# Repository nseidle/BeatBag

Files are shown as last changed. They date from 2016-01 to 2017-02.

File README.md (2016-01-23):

BeatBag - A Speed Bag Counter
=======

BeatBag is a speed bag counter that uses an accelerometer to counts the number hits. It's easily installed ontop of speed bag platform only needing an accelerometer attached to the top of platform. You don't have to alter the hitting surface or change out the swivel.

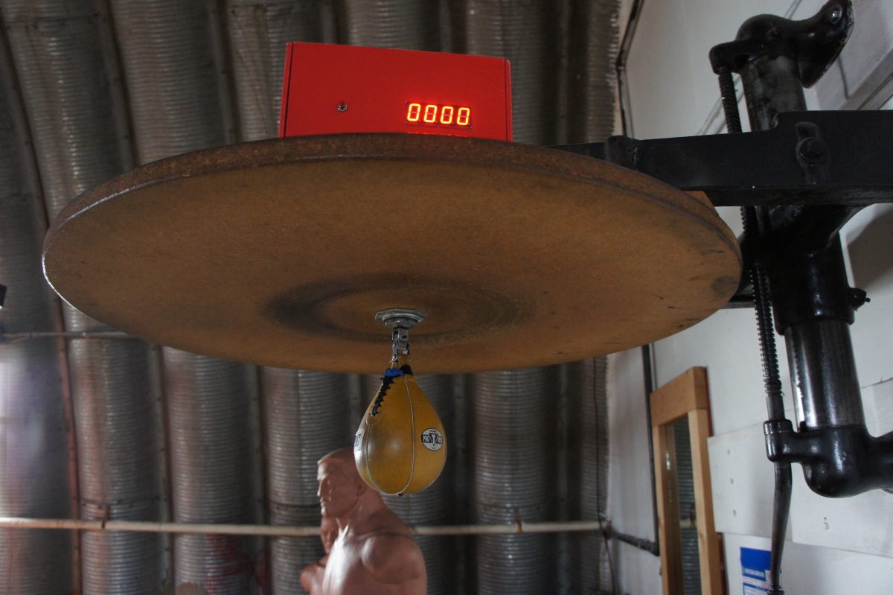
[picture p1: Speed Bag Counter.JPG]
BeatBag on top of a speed bag platform
  

License Information
-------------------

The hardware design and firmware are released under [Creative Commons Share-alike 3.0](http://creativecommons.org/licenses/by-sa/3.0/).  

Feel free to use, distribute, and sell varients of BeatBag. All I ask is that you include attribution of 'Based on BeatBag'.

The BeatBag firmware was created by Nathan Seidle, and is open source so please feel free to do anything you want with it; 
you buy me a beer if you use this and we meet someday ([Beerware license](http://en.wikipedia.org/wiki/Beerware)).

Repository Contents
-------------------
* **/Firmware** 
	* SpeedBagCounter - Firmware that runs on an Arduino or RedBoard
	* MMA8452 - The library to interface to the MMA8452 accelerometer
* **/Hardware** - Hardware design files for the PCB. These are unproven (never been built) but should work. If you're building your own use a RedBoard with OpenSegment and an MMA8452 breakout board.

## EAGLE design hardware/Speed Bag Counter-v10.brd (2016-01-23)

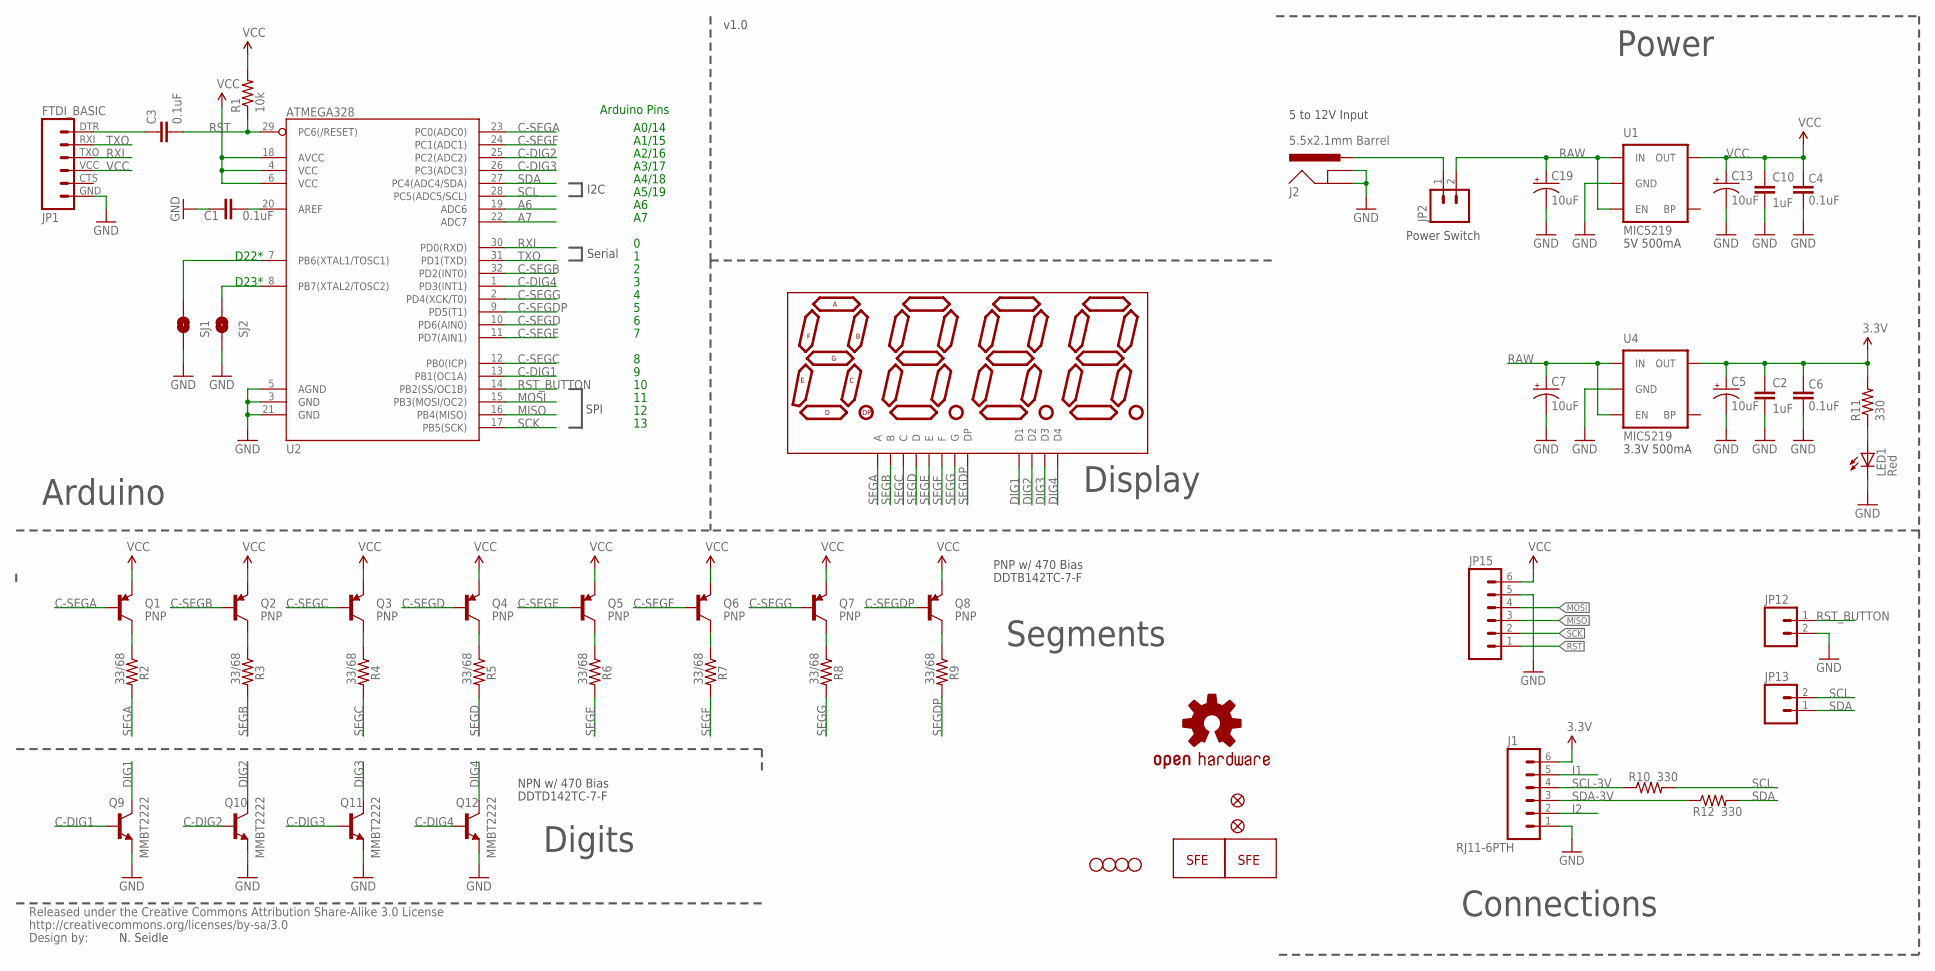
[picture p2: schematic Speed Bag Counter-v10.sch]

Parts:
C1, C3, C4, C6: 0.1uF; 0402-CAP
C2, C10: 1uF; 0402-CAP
C5, C7, C13, C19: 10uF; EIA3216
J1: RJ11-6PTH; RJ11-6
J2: 5.5x2.1mm Barrel; POWER_JACK_SMD
JP1: FTDI_BASIC
JP2, JP12: M02-JST-2MM-SMT; JST-2-SMD
JP3, JP4, JP5, JP6: STAND-OFF
JP7, JP14: FIDUCIALUFIDUCIAL; MICRO-FIDUCIAL
JP13: M02PTH; 1X02
JP15: M06SIP; 1X06
LED1: Red; LED-0603
Q1, Q2, Q3, Q4, Q5, Q6, Q7, Q8: PNP; SOT23-3
Q9, Q10, Q11, Q12: MMBT2222; SOT23-3
R1: 10k; 0402-RES
R2, R3, R4, R5, R6, R7, R8, R9: 33/68; 0402-RES
R10, R11, R12: 330; 0402-RES
SJ1, SJ2: Counter Ctl; SJ_2S-NO
U1, U4: MIC5219; SOT23-5
U2: ATMEGA328; TQFP32-08
U3: 7-SEGMENT-4DIGIT-COUNTERPTH; 7-SEGMENT-4DIGIT-COUNTER
U$2: LOGO-SFESK; SFE-LOGO-FLAME
U$3: CREATIVE_COMMONS
U$4: OSHW-LOGOS; OSHW-LOGO-S
U$7: LOGO-SFENW2; SFE-NEW-WEB

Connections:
3.3V: C2.1, C5.A (+), C6.2, J1.6, R11.2, U4.5 (OUT)
A6: U2.19 (ADC6)
A7: U2.22 (ADC7)
ANALOG: SJ2.1, U2.8 (PB7(XTAL2/TOSC2))
C-DIG1: Q9.1 (B), U2.13 (PB1(OC1A))
C-DIG2: Q10.1 (B), U2.25 (PC2(ADC2))
C-DIG3: Q11.1 (B), U2.26 (PC3(ADC3))
C-DIG4: Q12.1 (B), U2.1 (PD3(INT1))
C-SEGA: Q1.1 (B), U2.23 (PC0(ADC0))
C-SEGB: Q2.1 (B), U2.32 (PD2(INT0))
C-SEGC: Q3.1 (B), U2.12 (PB0(ICP))
C-SEGD: Q4.1 (B), U2.10 (PD6(AIN0))
C-SEGDP: Q8.1 (B), U2.9 (PD5(T1))
C-SEGE: Q5.1 (B), U2.11 (PD7(AIN1))
C-SEGF: Q6.1 (B), U2.24 (PC1(ADC1))
C-SEGG: Q7.1 (B), U2.2 (PD4(XCK/T0))
COUNTER: SJ1.1, U2.7 (PB6(XTAL1/TOSC1))
DIG1: Q9.3 (C), U3.12 (D1)
DIG2: Q10.3 (C), U3.9 (D2)
DIG3: Q11.3 (C), U3.8 (D3)
DIG4: Q12.3 (C), U3.6 (D4)
GND: C1.1, C2.2, C4.1, C5.C (-), C6.1, C7.C (-), C10.2, C13.C (-), C19.C (-), J1.1, J2.GND (GNDBREAK), J2.P$4 (GND), JP1.GND (6), JP12.2 (1), JP15.5, LED1.C, Q9.2 (E), Q10.2 (E), Q11.2 (E), Q12.2 (E), SJ1.2, SJ2.2, U1.2 (GND), U2.3 (GND), U2.5 (AGND), U2.21 (GND), U4.2 (GND)
I1: J1.5
I2: J1.2
MISO: JP15.3, U2.16 (PB4(MISO))
MOSI: JP15.4, U2.15 (PB3(MOSI/OC2))
unnamed: Q1.3 (C), R2.1
unnamed: J2.VIN0 (PWR), JP2.1 (2)
unnamed: C3.1, JP1.DTR (1)
unnamed: Q2.3 (C), R3.1
unnamed: Q3.3 (C), R4.1
unnamed: Q4.3 (C), R5.1
unnamed: Q5.3 (C), R6.1
unnamed: Q6.3 (C), R7.1
unnamed: Q7.3 (C), R8.1
unnamed: Q8.3 (C), R9.1
unnamed: C1.2, U2.20 (AREF)
unnamed: LED1.A, R11.1
RAW: C7.A (+), C19.A (+), JP2.2 (1), U1.1 (IN), U1.3 (EN), U4.1 (IN), U4.3 (EN)
RST: C3.2, JP15.1, R1.1, U2.29 (PC6(/RESET))
RST_BUTTON: JP12.1 (2), U2.14 (PB2(SS/OC1B))
RXI: JP1.TXO (3), U2.30 (PD0(RXD))
SCK: JP15.2, U2.17 (PB5(SCK))
SCL: JP13.2, R10.2, U2.28 (PC5(ADC5/SCL))
SCL-3V: J1.4, R10.1
SDA: JP13.1, R12.2, U2.27 (PC4(ADC4/SDA))
SDA-3V: J1.3, R12.1
SEGA: R2.2, U3.11 (A)
SEGB: R3.2, U3.7 (B)
SEGC: R4.2, U3.4 (C)
SEGD: R5.2, U3.2 (D)
SEGDP: R9.2, U3.3 (DP)
SEGE: R6.2, U3.1 (E)
SEGF: R7.2, U3.10 (F)
SEGG: R8.2, U3.5 (G)
TXO: JP1.RXI (2), U2.31 (PD1(TXD))
VCC: C4.2, C10.1, C13.A (+), JP1.VCC (4), JP15.6, Q1.2 (E), Q2.2 (E), Q3.2 (E), Q4.2 (E), Q5.2 (E), Q6.2 (E), Q7.2 (E), Q8.2 (E), R1.2, U1.5 (OUT), U2.4 (VCC), U2.6 (VCC), U2.18 (AVCC)

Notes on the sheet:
N. Seidle
A0/14
A1/15
A2/16
A3/17
A4/18
A5/19
Arduino Pins
5V 500mA
SPI
v1.0
Serial
I2C
Arduino
Display
Segments
Digits
Connections
Power
D22*
D23*
5 to 12V Input
NPN w/ 470 Bias
DDTD142TC-7-F
PNP w/ 470 Bias
DDTB142TC-7-F
3.3V 500mA
Power Switch

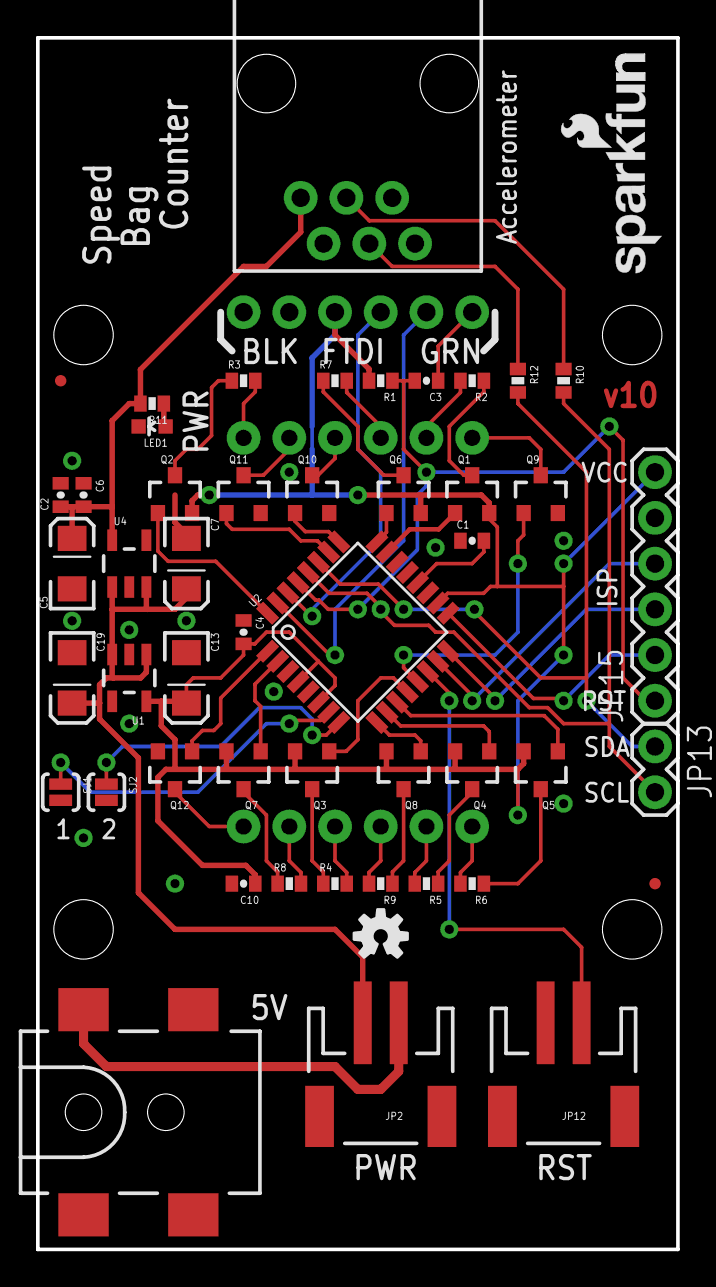
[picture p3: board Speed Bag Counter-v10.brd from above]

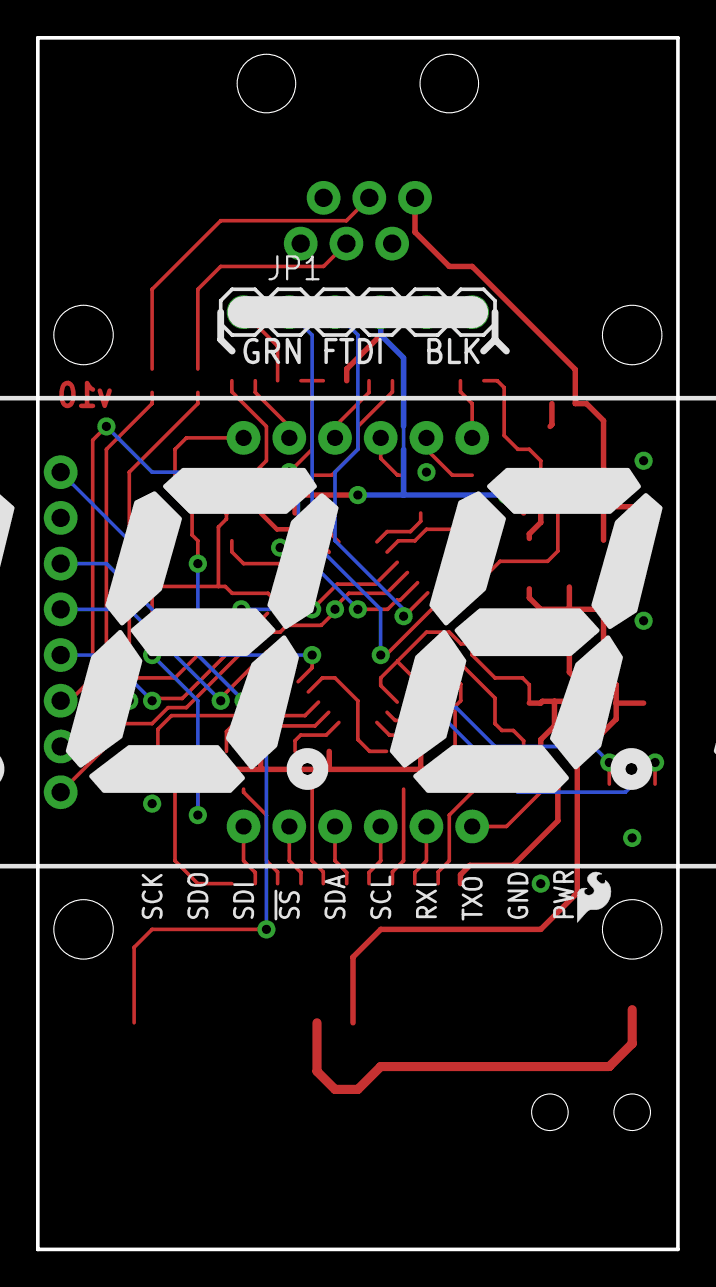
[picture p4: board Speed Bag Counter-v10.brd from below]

Board: 2 copper layers, 35.6 x 67.3 mm, 59 parts (3 on the bottom side), 53 nets.

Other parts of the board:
U$1: LOGO-SFESK; SFE-LOGO-FLAME

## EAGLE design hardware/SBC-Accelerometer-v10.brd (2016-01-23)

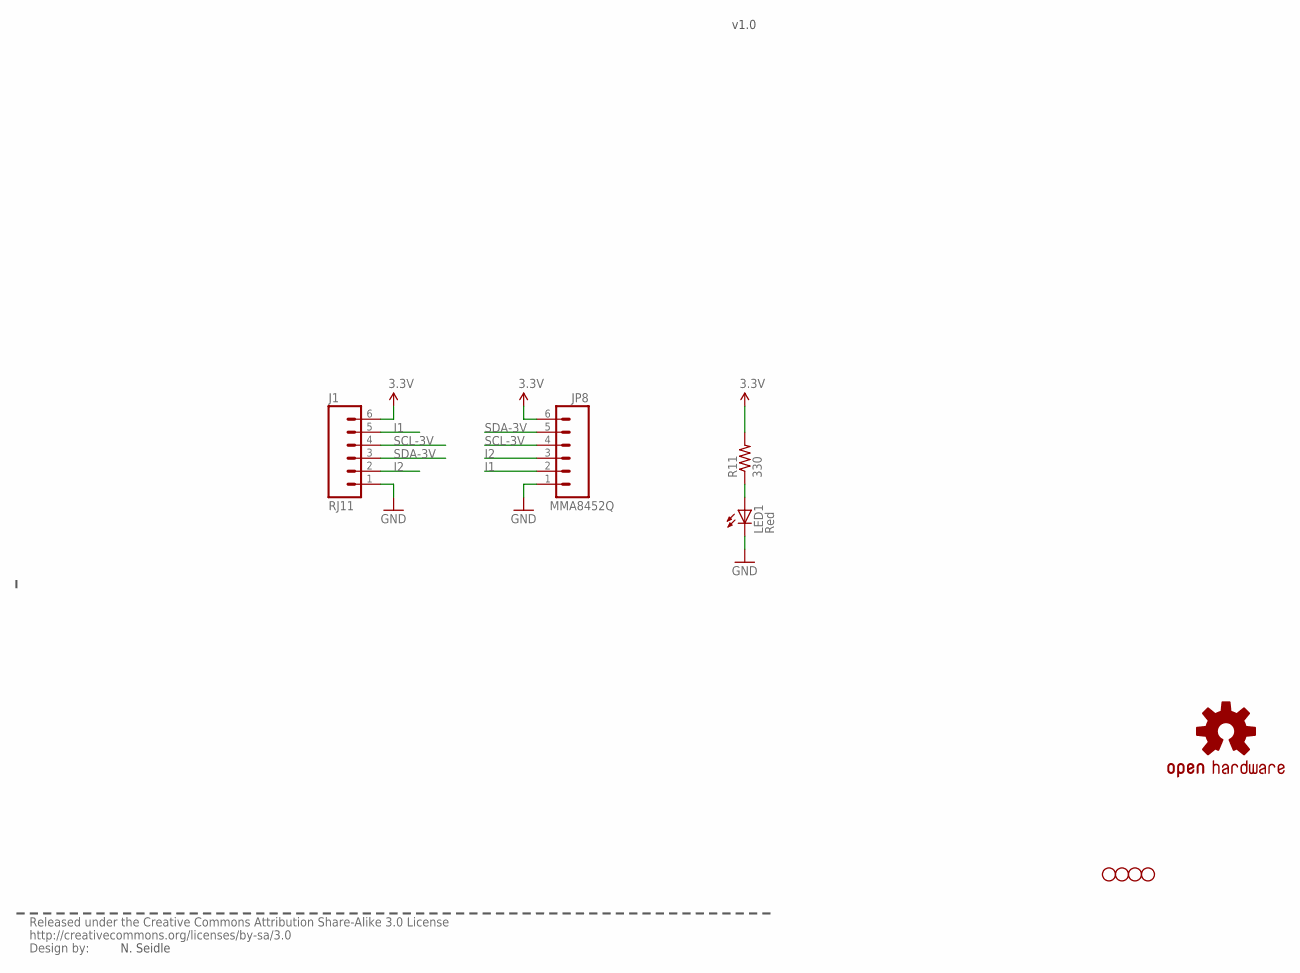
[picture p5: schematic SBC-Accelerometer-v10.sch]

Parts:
J1: RJ11; RJ11-6
JP3, JP4, JP5, JP6: STAND-OFF
JP8: MMA8452Q; 1X06
LED1: Red; LED3MM
R11: 330; AXIAL-0.3
U$3: CREATIVE_COMMONS
U$4: OSHW-LOGOS; OSHW-LOGO-S

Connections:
3.3V: J1.6, JP8.6, R11.P$2 (2)
GND: J1.1, JP8.1, LED1.K (C)
I1: J1.5, JP8.2
I2: J1.2, JP8.3
unnamed: LED1.A, R11.P$1 (1)
SCL-3V: J1.4, JP8.4
SDA-3V: J1.3, JP8.5

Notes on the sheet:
N. Seidle
v1.0

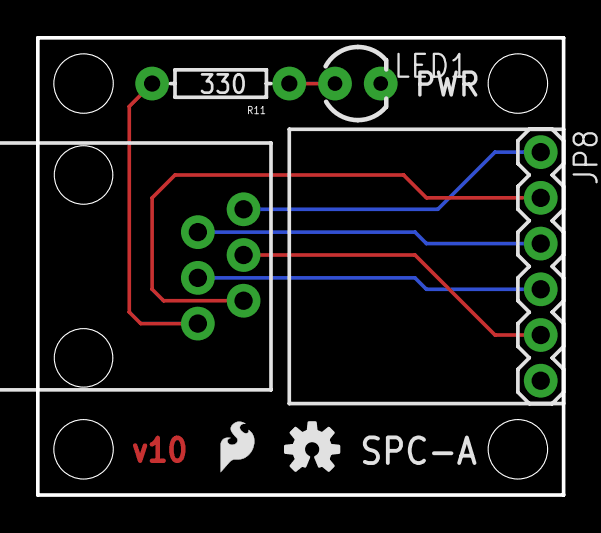
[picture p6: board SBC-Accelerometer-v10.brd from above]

Board: 2 copper layers, 29.2 x 25.4 mm, 11 parts (0 on the bottom side), 7 nets.

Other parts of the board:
U$1: LOGO-SFESK; SFE-LOGO-FLAME

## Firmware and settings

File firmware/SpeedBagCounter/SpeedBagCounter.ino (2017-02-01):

/*
  BeatBag - A Speed Bag Counter
  Nathan Seidle
  SparkFun Electronics
  2/23/2013

  License: This code is public domain but you buy me a beer if you use this and we meet someday (Beerware license).

  BeatBag is a speed bag counter that uses an accelerometer to counts the number hits.
  It's easily installed ontop of speed bag platform only needing an accelerometer attached to the top of platform.
  You don't have to alter the hitting surface or change out the swivel.

  I combine X/Y/Z into one vector and look only at the magnitude.
  I use a fourth order filter to see the impacts (accelerometer peaks) from the speed bag. It works pretty well.
  It's very reproducible but I'm not entirely sure how accurate it is. I can detect both bag hits (forward/backward) then
  I divide by two to get the number displayed to the user.

  I arrived at the peak detection algorithm using video and raw data recordings. After a fourth filtering I could glean the
  peaks. There is probably a much better way to do the math on the peak detection but it's not one of my strength.

  Hardware setup:
  5V from wall supply goes into barrel jack on Redboard. Trace cut to diode.
  RedBoard barel jack is wired to power switch then to Vin diode
  Display gets power from Vin and data from I2C pins
  Vcc/Gnd from RedBoard goes into Bread Board Power supply that supplies 3.3V to accelerometer. Future
  versions should get power from 3.3V rail on RedBoard.

  MMA8452 Breakout ------------ Arduino
  3.3V --------------------- 3.3V
  SDA(yellow) -------^^(330)^^------- A4
  SCL(blue) -------^^(330)^^------- A5
  GND ---------------------- GND
  The MMA8452 is 3.3V so we recommend using 330 or 1k resistors between a 5V Arduino and the MMA8452 breakout.
  The MMA8452 has built in pull-up resistors for I2C so you do not need additional pull-ups.

  3/2/2013 - Got data from Hugo and myself, 3 rounds, on 2g setting. Very noisy but mostly worked

  12/19/15 - Segment burned out. Power down display after 10 minutes of non-use.
  Use I2C, see if we can avoid the 'multiply by 10' display problem.

  1/23/16 - Accel not reliable. Because the display is now also on the I2C the pull-up resistors on the accel where
  not enough. Swapped out to new accel. Added 100 ohm inline resistors to accel and 4.7k resistors from SDA/SCL to 5V.
  Reinforced connection from accel to RedBoard.

  7/30/16 - Converting to SAMD21 Mini. Pulling in barryh's filter: https://github.com/barryhannigan/SpeedBagChallenge

  12/2/16 - Milled enclosure: https://cad.onshape.com/documents/b296a359e264985023b853b6/w/9eb5ce54572ff50af782cbe7/e/9ed5980190f87b54f97fe0e4

  1/31/17 - Changed the way the display powered down.

*/

#include <Wire.h> // Used for I2C
#include "AccelData.h"
#include "FEP.h"
#include "DET.h"

#define DISPLAY_ADDRESS 0x71 //I2C address of OpenSegment display

int hitCounter = 0; //Keeps track of the number of hits

const int LED = 13; //Status LED on D3

long lastPrint; //Used for printing updates every second

boolean displayOn; //Used to track if display is turned off or not

//Used in the new algorithm
float lastMagnitude = 0;
float lastFirstPass = 0;
float lastSecondPass = 0;
float lastThirdPass = 0;
long lastHitTime = 0;
int secondsCounter = 0;

//This was found using a spreadsheet to view raw data and filter it
const float WEIGHT = 0.9;

//This was found using a spreadsheet to view raw data and filter it
const int MIN_MAGNITUDE_THRESHOLD = 1000; //350 is good

//This is the minimum number of ms between possible hits
//We use this to filter out peaks that are too close together
const int MIN_TIME_BETWEEN_HITS = 90; //100 works well

//This is the number of miliseconds before we turn off the display
long TIME_TO_DISPLAY_OFF = 60L * 1000L * 5L; //5 minutes of no use
//long TIME_TO_DISPLAY_OFF = 10L * 1000L; //For testing

int DEFAULT_BRIGHTNESS = 50; //50% brightness to avoid burning out segments after 3 years of use

unsigned long currentTime; //Used for millis checking

AccelData newData;
FEPFilterKernel fep;
DETFilterKernel det;

void setup()
{
  pinMode(LED, OUTPUT);

  //By default .begin() will set I2C SCL to Standard Speed mode of 100kHz
  Wire.setClock(400000); //Optional - set I2C SCL to High Speed Mode of 400kHz
  Wire.begin(); //Join the bus as a master

  SerialUSB.begin(115200);
  SerialUSB.println("Speed Bag Counter");

  initDisplay();

  //clearDisplay();
  Wire.beginTransmission(DISPLAY_ADDRESS);
  Wire.print("Accl"); //Display an error until accel comes online
  Wire.endTransmission();

  while (!initMMA8452()) //Test and intialize the MMA8452
    ; //Do nothing

  //clearDisplay();
  Wire.beginTransmission(DISPLAY_ADDRESS);
  Wire.print("0000");
  Wire.endTransmission();

  displayOn = true;

  lastPrint = millis();
  lastHitTime = millis();

  // Initialize and prime the FIR Filters
  FEP_init();
  FEPFilter_init(&fep);
  DET_init();
  DETFilter_init(&det);
  AccelData dummyData;
  getAccelData(&dummyData);
  for (int i = 0; i < FEPFilterKernel::FILTER_TAP_NUM; i++)
  {
    //System.out.println("Priming Filter");
    FEPFilter_put(&fep, &dummyData);
  }
  for (int i = 0; i < DETFilterKernel::FILTER_TAP_NUM; i++)
  {
    //System.out.println("Priming Filter");
    FEPFilter_put(&fep, &dummyData);
    DETFilter_put(&det, FEPFilter_get(&fep));
  }
}

void loop()
{
  currentTime = millis();
  if ((unsigned long)(currentTime - lastPrint) >= 1000)
  {
    if (digitalRead(LED) == LOW)
      digitalWrite(LED, HIGH);
    else
      digitalWrite(LED, LOW);

    lastPrint = millis();
  }

  //See if we should power down the display due to inactivity
  if (displayOn == true)
  {
    currentTime = millis();

    if ((unsigned long)(currentTime - lastHitTime) >= TIME_TO_DISPLAY_OFF)
    {
      SerialUSB.println("Power save");

      hitCounter = 0; //Reset the count

      clearDisplay(); //Clear to save power
      displayOn = false;
    }
  }

  getAccelData(&newData);
  //printf("Timestamp = %d, z = %d\n", newData.timeStamp, newData.z);
  FEPFilter_put(&fep, &newData);
  AccelData* fepData = FEPFilter_get(&fep);
  DETFilter_put(&det, fepData);
  AccelData* detData = DETFilter_get(&det);
  if (detData->maxZFound > 0)
  {
    //We really do have a hit!
    hitCounter++;

    //SerialUSB.print("Hit: ");
    //SerialUSB.println(hitCounter);
    
    lastHitTime = millis(); //Record when we got this hit

    if (displayOn == false)
    {
      initDisplay(); //Bring it back on
    }

    printHits(); //Updates the display
  }
  
}

//This function makes sure the display is at 57600
void initDisplay()
{
  resetDisplay(); //Forces cursor to beginning of display

  printHits(); //Update display with current hit count

  displayOn = true;

  setBrightness(DEFAULT_BRIGHTNESS);
}

//Set brightness of display
void setBrightness(int brightness)
{
  Wire.beginTransmission(DISPLAY_ADDRESS);
  Wire.write(0x7A); // Brightness control command
  Wire.write(brightness); // Set brightness level: 0% to 100%
  Wire.endTransmission();
}

void resetDisplay()
{
  //Send the reset command to the display - this forces the cursor to return to the beginning of the display
  Wire.beginTransmission(DISPLAY_ADDRESS);
  Wire.write('v');
  Wire.endTransmission();

  if (displayOn == false)
  {
    setBrightness(DEFAULT_BRIGHTNESS); //Power up display
    displayOn = true;
    lastHitTime = millis();
  }
}

//Push the current hit counter to the display
void printHits()
{
  int tempCounter = hitCounter / 2; //Cut in half

  Wire.beginTransmission(DISPLAY_ADDRESS);
  Wire.write(0x79); //Move cursor
  Wire.write(4); //To right most position

  Wire.write(tempCounter / 1000); //Send the left most digit
  tempCounter %= 1000; //Now remove the left most digit from the number we want to display
  Wire.write(tempCounter / 100);
  tempCounter %= 100;
  Wire.write(tempCounter / 10);
  tempCounter %= 10;
  Wire.write(tempCounter); //Send the right most digit

  Wire.endTransmission(); //Stop I2C transmission
}

//Clear display to save power (a screen saver of sorts)
void clearDisplay()
{
  Wire.beginTransmission(DISPLAY_ADDRESS);
  Wire.write(0x79); //Move cursor
  Wire.write(4); //To right most position

  Wire.write(' ');
  Wire.write(' ');
  Wire.write(' ');
  Wire.write(' ');

  Wire.endTransmission(); //Stop I2C transmission
}

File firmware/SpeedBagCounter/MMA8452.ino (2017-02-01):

/*
  These are all the functions that make the MMA8452 tick
*/
// The SparkFun breakout board defaults to 1, set to 0 if SA0 jumper on the bottom of the board is set
#define MMA8452_ADDRESS 0x1D  // 0x1D if SA0 is high, 0x1C if low

//Define a few of the registers that we will be accessing on the MMA8452
#define OUT_X_MSB 0x01
#define XYZ_DATA_CFG  0x0E
#define WHO_AM_I   0x0D
#define CTRL_REG1  0x2A

#define GSCALE 4 // Sets full-scale range to +/-2, 4, or 8g. Used to calc real g values.

#define MAXTIME 10 //Number of milliseconds before we give up. 100 worked well. 10 works well too.
#define TIMEOUT_ERROR 255 //Return 255 on the case of error. Should work for functions that return bytes

volatile unsigned int timeOutCounter = 0;

//Checks the accelerometer and converts the readings to actual g values
//Returns an array containing the float values.
void getAccelData(AccelData* dataPtr)
{
  int accelCount[3];  // Stores the 12-bit signed value
  readAccelData(accelCount);  // Read the x/y/z adc values
  dataPtr->timeStamp = millis();
  dataPtr->minZFound = 0;
  dataPtr->maxZFound = 0;
  dataPtr->z = accelCount[2]; // Only using Z now
  
  //Print the readings for logging to an OpenLog
  /*SerialUSB.print(millis());
  SerialUSB.print(",");
  SerialUSB.print(accelCount[0]);
  SerialUSB.print(",");
  SerialUSB.print(accelCount[1]);
  SerialUSB.print(",");
  SerialUSB.println(accelCount[2]);*/
}

void readAccelData(int *destination)
{
  byte rawData[6];  // x/y/z accel register data stored here

  if(readRegisters(OUT_X_MSB, 6, rawData) == TIMEOUT_ERROR)  // Read the six raw data registers into data array
  {
    SerialUSB.print("Accel reponse timeout: ");
    SerialUSB.println(timeOutCounter);

    while(readRegisters(OUT_X_MSB, 6, rawData) == TIMEOUT_ERROR)
    {
      //Restart the accel
      if(!initMMA8452()) //Test and intialize the MMA8452
      {
        clearDisplay();
        Wire.beginTransmission(DISPLAY_ADDRESS);
        Wire.print("Accl");
        Wire.endTransmission();
      }
    }

    //Reset global vars
    lastPrint = millis();
    lastHitTime = millis();
    
    lastMagnitude = 0;
    lastFirstPass = 0;
    lastSecondPass = 0;
    lastThirdPass = 0;
  }

  // Loop to calculate 12-bit raw accel value
  for(int i = 0; i < 3 ; i++)
  {
    int gCount = (rawData[i*2] << 8) | rawData[(i*2)+1];  //Combine the two 8 bit registers into one 12-bit number
    gCount >>= 4; //The registers are left align, here we right align the 12-bit integer

    // If the number is negative, we have to make it so manually (no 12-bit data type)
    if (rawData[i*2] > 0x7F)
    {  
      gCount = ~gCount + 1;
      gCount *= -1;  // Transform into negative 2's complement #
    }

    destination[i] = gCount; //Record this gCount into the 3 int array
  }
}

// Initialize the MMA8452 registers 
// See the many application notes for more info on setting all of these registers:
// http://www.freescale.com/webapp/sps/site/prod_summary.jsp?code=MMA8452Q
boolean initMMA8452()
{
  byte c = readRegister(WHO_AM_I);  // Read WHO_AM_I register
  if (c == 0x2A) // WHO_AM_I should always be 0x2A
  {  
    SerialUSB.println("Accel initialized");
  }
  else
  {
    SerialUSB.println("Could not connect to accel");
    return(false);
  }

  MMA8452Standby();  // Must be in standby to change registers

  // Set up the full scale range to 2, 4, or 8g.
  byte fsr = GSCALE;
  if(fsr > 8) fsr = 8; //Easy error check
  fsr >>= 2; // Neat trick, see page 22. 00 = 2G, 01 = 4A, 10 = 8G
  writeRegister(XYZ_DATA_CFG, fsr);

  //The default data rate is 800Hz and we don't modify it in this example code

  MMA8452Active();  // Set to active to start reading

  return(true);
}

// Sets the MMA8452 to standby mode. It must be in standby to change most register settings
void MMA8452Standby()
{
  byte c = readRegister(CTRL_REG1);
  writeRegister(CTRL_REG1, c & ~(0x01)); //Clear the active bit to go into standby
}

// Sets the MMA8452 to active mode. Needs to be in this mode to output data
void MMA8452Active()
{
  byte c = readRegister(CTRL_REG1);
  writeRegister(CTRL_REG1, c | 0x01); //Set the active bit to begin detection
}

// Read bytesToRead sequentially, starting at addressToRead into the dest byte array
byte readRegisters(byte addressToRead, int bytesToRead, byte * dest)
{
  Wire.beginTransmission(MMA8452_ADDRESS);
  Wire.write(addressToRead);
  Wire.endTransmission(false); //endTransmission but keep the connection active

  Wire.requestFrom(MMA8452_ADDRESS, bytesToRead); //Ask for bytes, once done, bus is released by default

  long startTime = millis();  
  while(Wire.available() < bytesToRead) //Hang out until we get the # of bytes we expect
  {
    if(millis() - startTime > MAXTIME) 
    {
      timeOutCounter++;
      return(TIMEOUT_ERROR);
    }
  }

  for(int x = 0 ; x < bytesToRead ; x++)
    dest[x] = Wire.read();    
}

// Read a single byte from addressToRead and return it as a byte
byte readRegister(byte addressToRead)
{
  Wire.beginTransmission(MMA8452_ADDRESS);
  Wire.write(addressToRead);
  Wire.endTransmission(false); //endTransmission but keep the connection active

  Wire.requestFrom(MMA8452_ADDRESS, 1); //Ask for 1 byte, once done, bus is released by default

  long startTime = millis();
  while(!Wire.available()) //Wait for the data to come back
  {
    if(millis() - startTime > MAXTIME) return(TIMEOUT_ERROR);    
  }
  
  return Wire.read(); //Return this one byte
}

// Writes a single byte (dataToWrite) into addressToWrite
void writeRegister(byte addressToWrite, byte dataToWrite)
{
  Wire.beginTransmission(MMA8452_ADDRESS);
  Wire.write(addressToWrite);
  Wire.write(dataToWrite);
  Wire.endTransmission(); //Stop transmitting
}

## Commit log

2016-01-23 Adding firmware and hardware files
    [SBC-Accelerometer-v10.brd, SBC-Accelerometer-v10.sch, Speed Bag Counter-v10.brd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]
2016-01-24 Fix for unresponsive accel. Adding pullup resistors to 5V bus.
    [AccelTest.ino, MMA8452.ino, SpeedBagCounter.ino]
2016-06-01 Cleaning up main sketch
    Removed the old code that used to record to an SD card directly. Easier
    to record to OpenLog via Serial.print() statements.
2017-02-01 Pulling in Barry's filter. Changing the display power down sequence.

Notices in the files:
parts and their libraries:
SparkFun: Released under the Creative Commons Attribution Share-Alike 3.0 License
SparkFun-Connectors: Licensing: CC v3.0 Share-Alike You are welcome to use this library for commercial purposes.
